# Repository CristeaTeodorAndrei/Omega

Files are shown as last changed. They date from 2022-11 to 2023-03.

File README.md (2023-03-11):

# OMEGA - Flight Computer

## OMEGA is the rocket's main flight computer.

### OMEGA flight computer is equipped with an Atmega328PB microcontroller. Attached to this microcontroller is an MPU6050 gyro sensor, a LoRa module for ground telemetry. 

#### NOTE: This is the first iteration of the flight computer

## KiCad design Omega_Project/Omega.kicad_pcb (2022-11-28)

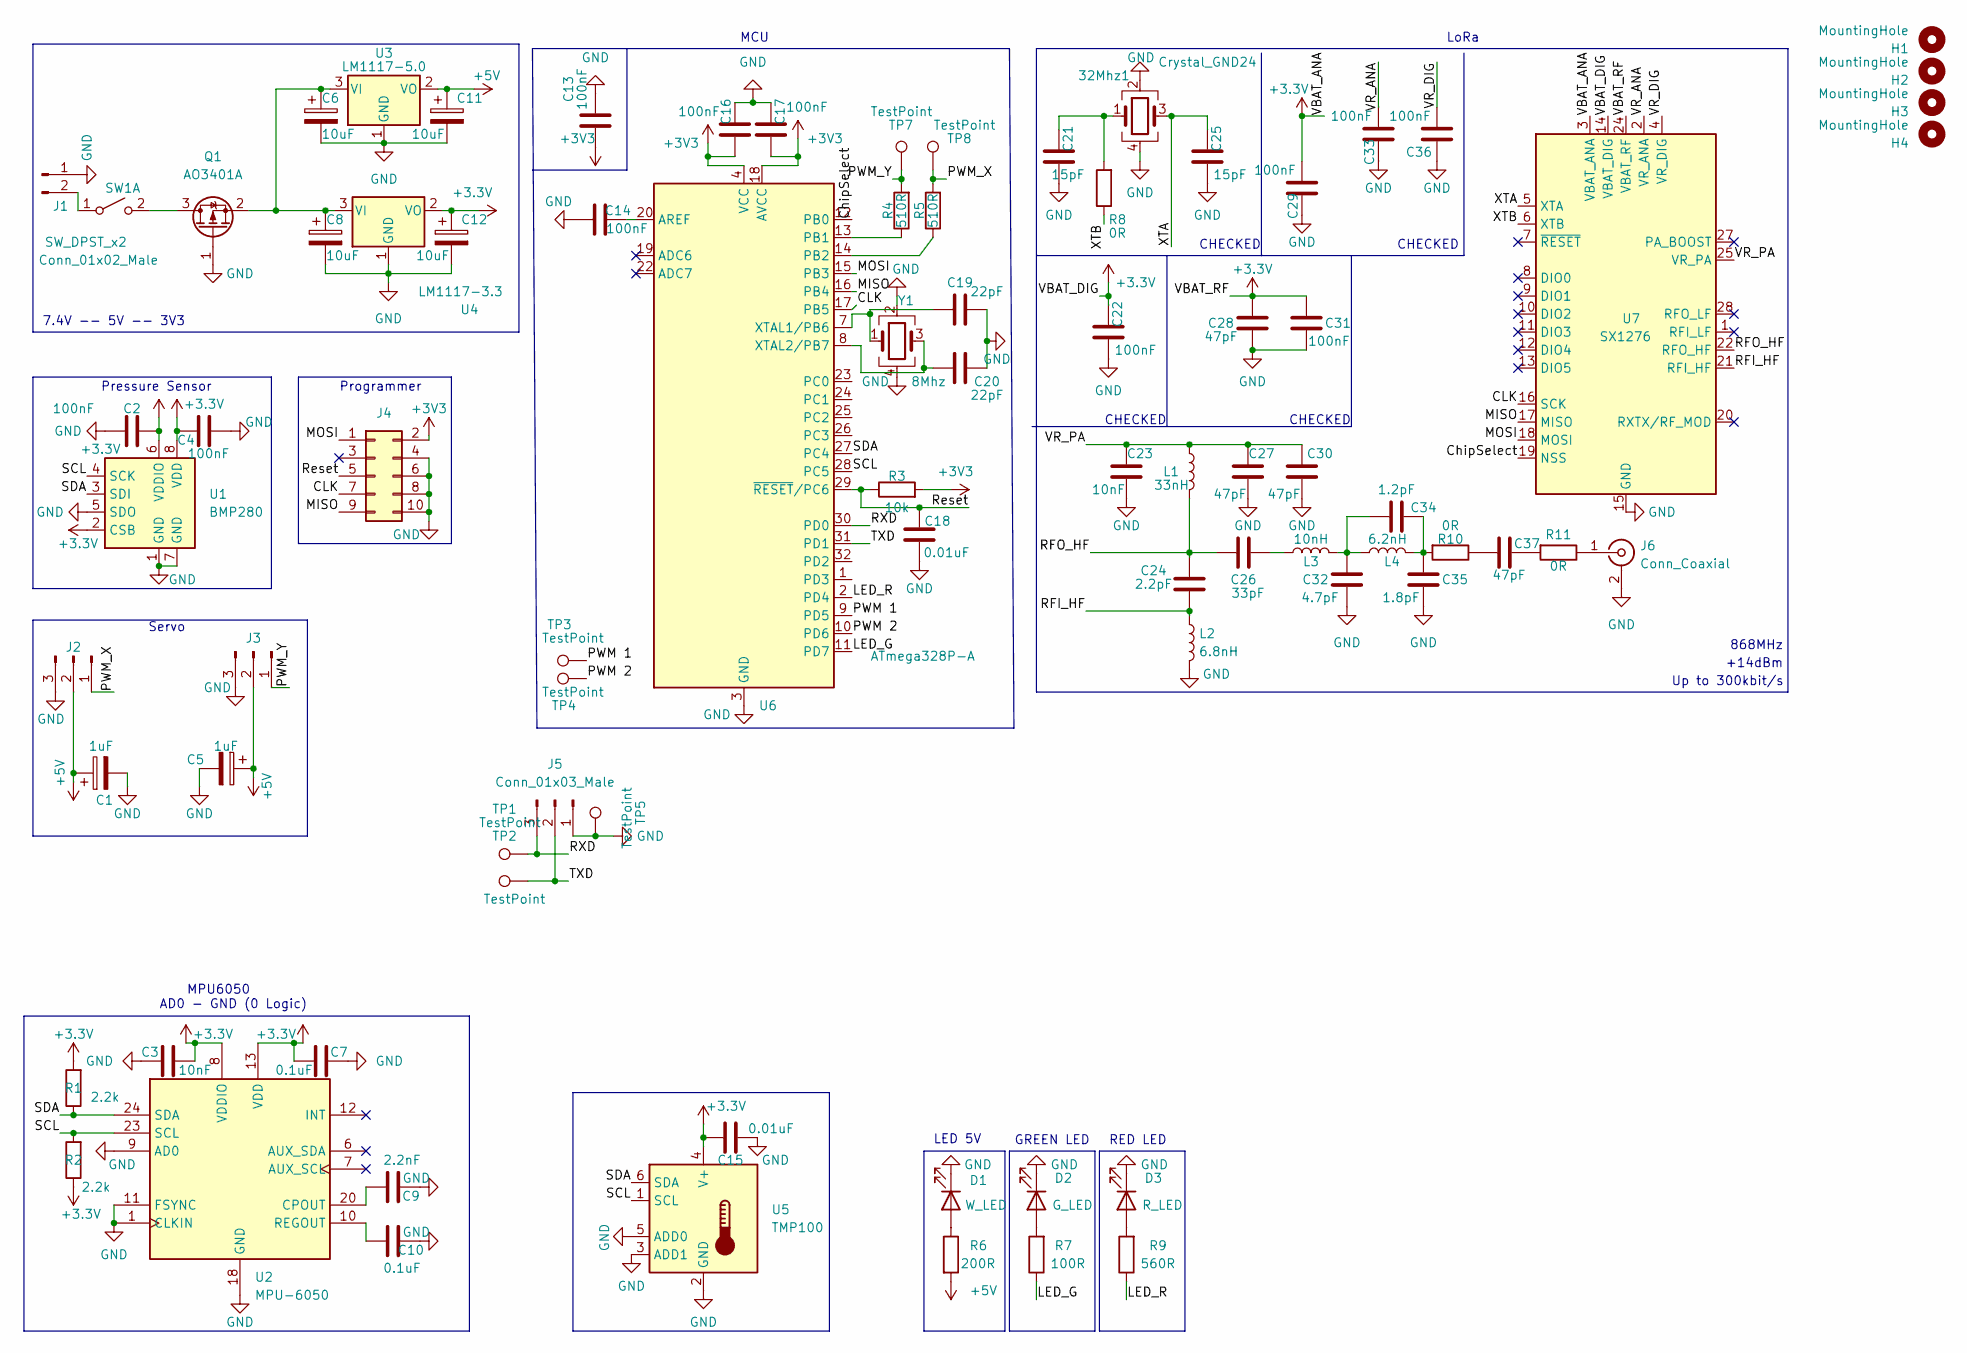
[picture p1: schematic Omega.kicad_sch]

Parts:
32Mhz1: Crystal_GND24; Crystal_SMD_2016-4Pin_2.0x1.6mm
C1, C5: 1uF; CP_Elec_4x5.4
C2, C4, C13, C14, C16, C17, C22, C29, C31, C33, C36: 100nF; C_0402_1005Metric
C3, C23: 10nF; C_0402_1005Metric
C6, C8, C11, C12: 10uF; C_1206_3216Metric
C7, C10: 0.1uF; C_0402_1005Metric
C9: 2.2nF; C_0402_1005Metric
C15, C18: 0.01uF; C_0402_1005Metric
C19, C20: 22pF; C_0402_1005Metric
C21, C25: 15pF; C_0402_1005Metric
C24: 2.2pF; C_0402_1005Metric
C26: 33pF; C_0402_1005Metric
C27, C28, C30, C37: 47pF; C_0402_1005Metric
C32: 4.7pF; C_0402_1005Metric
C34: 1.2pF; C_0402_1005Metric
C35: 1.8pF; C_0402_1005Metric
D1: W_LED; LED_PLCC-2
D2: G_LED; LED_PLCC-2
D3: R_LED; LED_PLCC-2
H1, H2, H3, H4: MountingHole; MountingHole_3.5mm
J1: Conn_01x02_Male; PinHeader_1x02_P2.54mm_Vertical
J2: X; PinHeader_1x03_P2.54mm_Vertical
J3: Y; PinHeader_1x03_P2.54mm_Vertical
J4: Conn_02x05_Odd_Even; IDC-Header_2x05_P2.54mm_Vertical
J5: Conn_01x03_Male; PinHeader_1x03_P2.54mm_Vertical
J6: Conn_Coaxial; SMA_Amphenol_132203-12_Horizontal
L1: 33nH; L_0402_1005Metric
L2: 6.8nH; L_0402_1005Metric
L3: 10nH; L_0402_1005Metric
L4: 6.2nH; L_0402_1005Metric
Q1: AO3401A; SOT-23
R1, R2: 2.2k; R_0402_1005Metric
R3: 10k; R_0402_1005Metric
R4, R5: 510R; R_0402_1005Metric
R6: 200R; R_0402_1005Metric
R7: 100R; R_0402_1005Metric
R8, R10, R11: 0R; R_0402_1005Metric
R9: 560R; R_0402_1005Metric
SW1: SW_DPST_x2; SW_DIP_SPSTx01_Slide_6.7x4.1mm_W6.73mm_P2.54mm_LowProfile_J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
TP1, TP2, TP3, TP4, TP5, TP7, TP8: TestPoint; TestPoint_Pad_D1.5mm
U1: BMP280; Bosch_LGA-8_2x2.5mm_P0.65mm_ClockwisePinNumbering
U2: MPU-6050; InvenSense_QFN-24_4x4mm_P0.5mm
U3: LM1117-5.0; SOT-223-3_TabPin2
U4: LM1117-3.3; SOT-223-3_TabPin2
U5: TMP100; SOT-23-6
U6: ATmega328P-A; TQFP-32_7x7mm_P0.8mm
U7: SX1276; QFN-28-1EP_6x6mm_P0.65mm_EP4.8x4.8mm
Y1: 8Mhz; Crystal_SMD_5032-4Pin_5.0x3.2mm

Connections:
+5V: C1.1, C5.1, C11.1, J2.2, J3.2, R6.2, U3.2 (VO)
/CLK: J4.7, U6.17 (PB5), U7.16 (SCK)
/ChipSelect: U6.12 (PB0), U7.19 (NSS)
/LED_G: R7.1, U6.11 (PD7)
/LED_R: R9.1, U6.2 (PD4)
/MISO: J4.9, U6.16 (PB4), U7.17 (MISO)
/MOSI: J4.1, U6.15 (PB3), U7.18 (MOSI)
/PWM 1: TP3.1, U6.9 (PD5)
/PWM 2: TP4.1, U6.10 (PD6)
/PWM_X: J2.1, R5.2, TP8.1
/PWM_Y: J3.1, R4.2, TP7.1
/RFI_HF: C24.1, L2.1, U7.21 (RFI_HF)
/RFO_HF: C24.2, C26.2, L1.2, U7.22 (RFO_HF)
/RXD: J5.3, TP1.1, U6.30 (PD0)
/Reset: C18.1, J4.5, R3.1, U6.29 (~RESET/PC6)
/SCL: R2.2, U1.4 (SCK), U2.23 (SCL), U5.1 (SCL), U6.28 (PC5)
/SDA: R1.1, U1.3 (SDI), U2.24 (SDA), U5.6 (SDA), U6.27 (PC4)
/TXD: J5.2, TP2.1, U6.31 (PD1)
/VR_ANA: C33.1, U7.2 (VR_ANA)
/VR_DIG: C36.1, U7.4 (VR_DIG)
/VR_PA: C23.2, C27.2, C30.2, L1.1, U7.25 (VR_PA)
/XTA: 32Mhz1.3, C25.2, U7.5 (XTA)
/XTB: R8.1, U7.6 (XTB)
GND: 32Mhz1.2, 32Mhz1.4, C1.2, C2.1, C3.1, C4.1, C5.2, C6.2, C7.2, C8.2, C9.2, C10.2, C11.2, C12.2, C13.2, C14.1, C15.2, C16.2, C17.2, C18.2, C19.2, C20.2, C21.1, C22.1, C23.1, C25.1, C27.1, C28.1, C29.2, C30.1, C31.1, C32.2, C33.2, C35.2, C36.2, D1.1 (K), D2.1 (K), D3.1 (K), J1.1, J2.3, J3.3, J4.4, J4.6, J4.8, J4.10, J5.1, J6.2 (Ext), L2.2, Q1.1 (G), TP5.1, U1.1 (GND), U1.5 (SDO), U1.7 (GND), U2.1 (CLKIN), U2.9 (AD0), U2.11 (FSYNC), U2.18 (GND), U3.1 (GND), U4.1 (GND), U5.2 (GND), U5.3 (ADD1), U5.5 (ADD0), U6.3 (GND), U6.5 (GND), U6.21 (GND), U7.15 (GND), U7.23 (GND), U7.26 (GND), U7.29 (GND), Y1.2, Y1.4
unnamed: 32Mhz1.1, C21.2, R8.2
unnamed: C6.1, C8.1, Q1.2 (S), U3.3 (VI), U4.3 (VI)
unnamed: C9.1, U2.20 (CPOUT)
unnamed: C10.1, U2.10 (REGOUT)
unnamed: C14.2, U6.20 (AREF)
unnamed: C19.1, U6.7 (XTAL1/PB6), Y1.1
unnamed: C20.1, U6.8 (XTAL2/PB7), Y1.3
unnamed: C26.1, L3.1
unnamed: C32.1, C34.2, L3.2, L4.1
unnamed: C34.1, C35.1, L4.2, R10.2
unnamed: C37.1, R10.1
unnamed: C37.2, R11.2
unnamed: D1.2 (A), R6.1
unnamed: D2.2 (A), R7.2
unnamed: D3.2 (A), R9.2
unnamed: J1.2, SW1.1 (A)
unnamed: J6.1 (In), R11.1
unnamed: Q1.3 (D), SW1.2 (B)
unnamed: R4.1, U6.13 (PB1)
unnamed: R5.1, U6.14 (PB2)

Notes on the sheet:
CHECKED
LED 5V
868MHz
Pressure Sensor
Up to 300kbit/s
Programmer
MPU6050 AD0 - GND (0 Logic)
MCU
RED LED
+14dBm
7.4V -- 5V -- 3V3
Servo
GREEN LED
LoRa

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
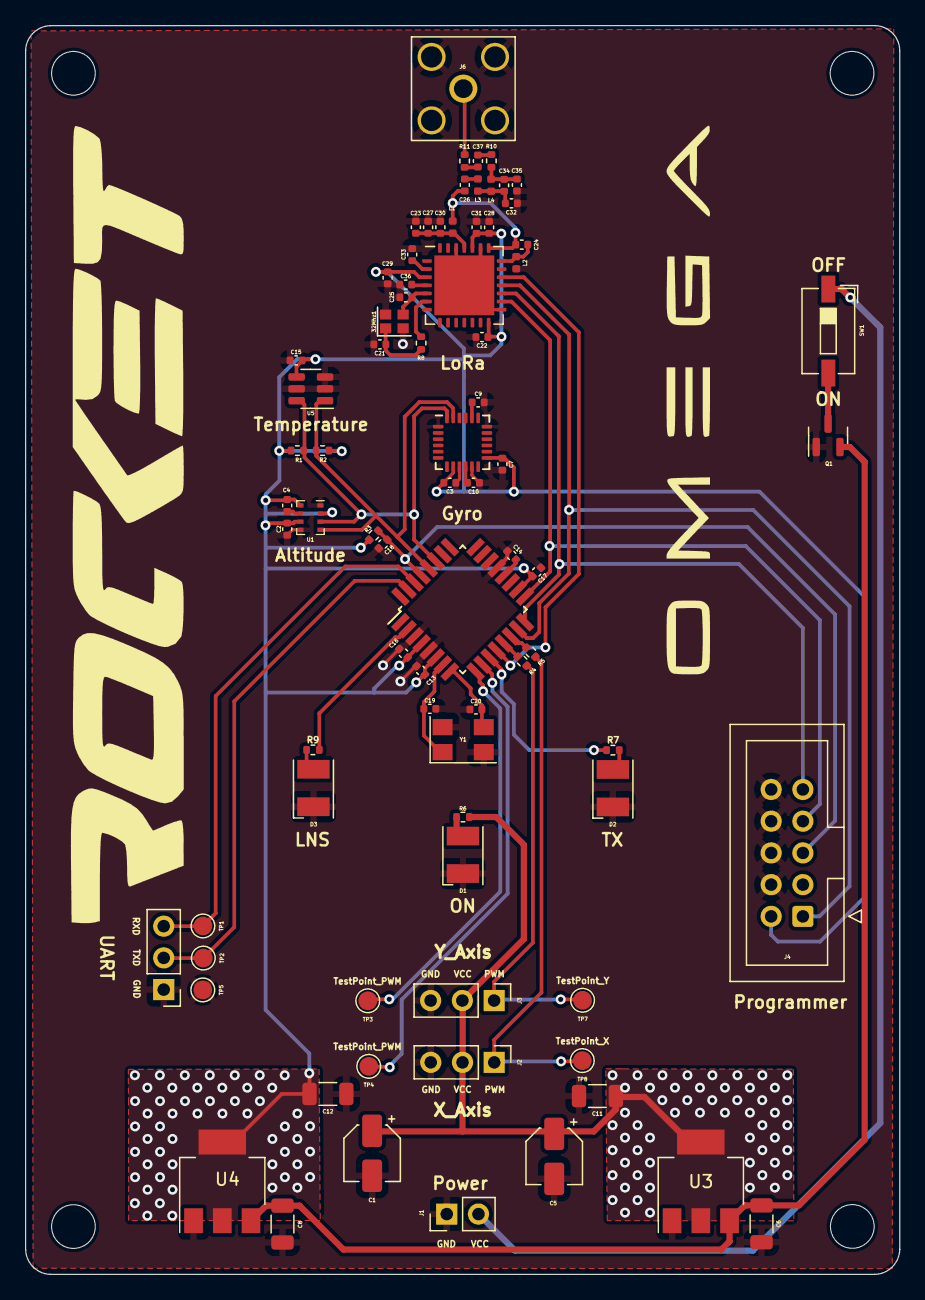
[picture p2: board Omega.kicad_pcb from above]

Board: 2 copper layers, 70.0 x 100.0 mm, 84 parts (0 on the bottom side), 45 nets.

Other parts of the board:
G2: LOGO; Logo

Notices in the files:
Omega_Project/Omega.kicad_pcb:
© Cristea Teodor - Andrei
